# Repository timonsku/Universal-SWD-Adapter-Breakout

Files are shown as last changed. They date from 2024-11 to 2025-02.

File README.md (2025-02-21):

# Universal-SWD-Adapter-Breakout

A simple PCB to adapt between common SWD connector variations.
- 20pin 0.1" Cortex SWD connector (as found on the big J-Link's)
- 10pin 0.1" Cortex SWD connector (as found on ST-Link)
- 10pin 0.05" Cortex SWD connector (as found on J-Link Mini and many targets) 
- Named 0.1" pin header row for all 6 main signals
- 6pin 0.1" TC2030-IDC footprint (compact "SWD-Adapter" only) 

There are two variants, one compact version and an expanded version that add an RJ12 connector intended to be used with the TC2030-MCP-NL Tag Connect cables which are used on Microchip programmers and are often the cheapest and easiest to buy Tag Connect cable from distributors. This variant is also useful for having some solder on pads for hard wiring an SWD connection to a device.

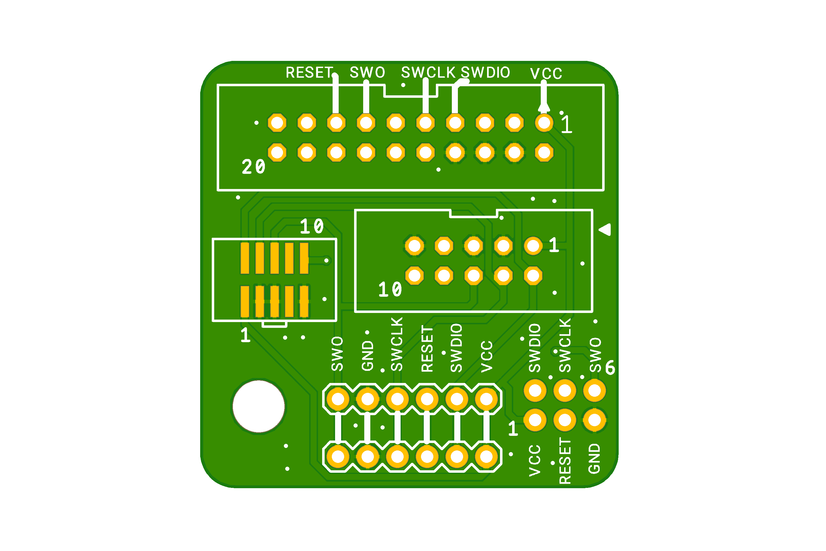
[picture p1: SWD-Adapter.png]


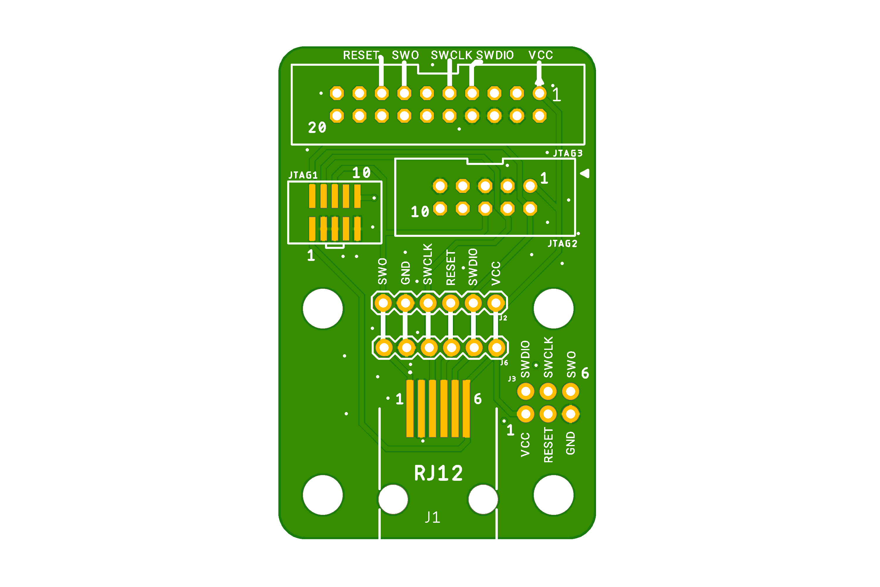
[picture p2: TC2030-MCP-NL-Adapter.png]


BOM
----

- Molex 95501-6669 (RJ12)
- Samtec FTSH-105-01-L-DV-K-TR (2x5 pin 1.27mm SMT shrouded). Cheaper here on AliExpress: https://s.click.aliexpress.com/e/_DmALpMt
- Molex 90130-1110 (2x5 2.54mm PTH Shrouded)
- Molex 90130-1120 (2x10 2.54mm PTH Shrouded)

Various distributor PNs the RJ12 tag connect cable:

NL version:
- 579-TC2030-MCP-NL 

With hooks:
- 733-53025-851
- 579-TC2030-MCP

For DigiKey:
- TC2030-MCP-NLTC-ND
- TC2030-MCPTC-ND

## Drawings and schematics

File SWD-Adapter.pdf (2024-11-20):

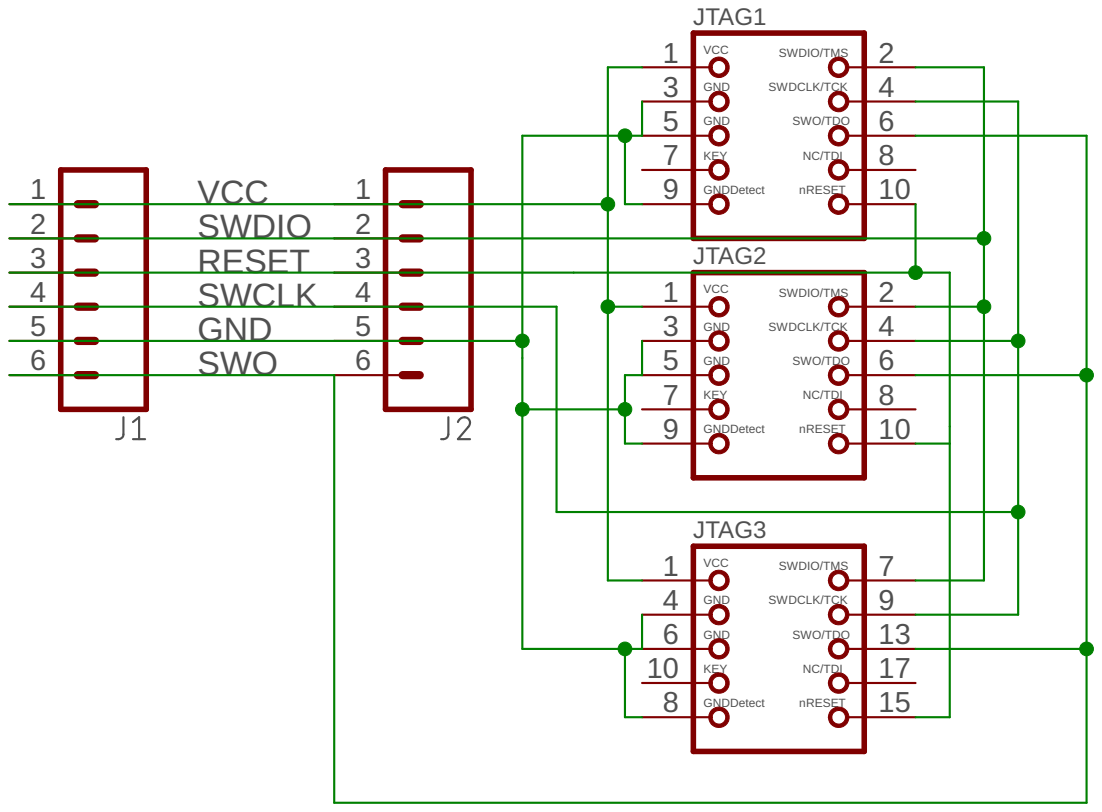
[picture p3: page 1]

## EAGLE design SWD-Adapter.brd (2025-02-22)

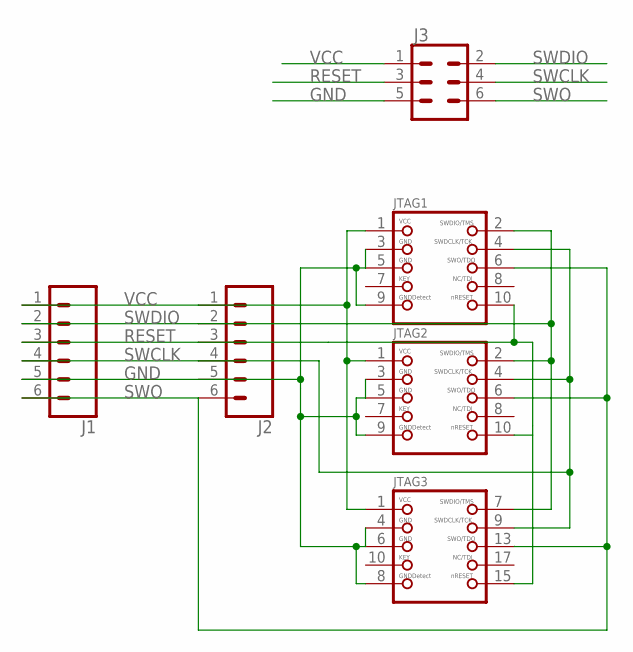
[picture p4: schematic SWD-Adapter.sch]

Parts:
J1, J2: CONN_06SILK_FEMALE_PTH; 1X06
J3: CONN_03X2NO_SILK; 2X3-NS
JTAG1: JTAG-CORTEXM3; 2X05_1.27MM_SMT
JTAG2: JTAG-CORTEXM3MOLEX; CORTEXM3_SWD10_MOLEX
JTAG3: JTAG-CORTEXM3MOLEX20; JTAG-ARM

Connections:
GND: J1.5, J2.5, J3.5, JTAG1.3, JTAG1.5, JTAG1.9, JTAG2.3, JTAG2.5, JTAG2.9, JTAG3.4 (3), JTAG3.6 (5), JTAG3.8 (9)
RESET: J1.3, J2.3, J3.3, JTAG1.10, JTAG2.10, JTAG3.15 (10)
SWCLK: J1.4, J2.4, J3.4, JTAG1.4, JTAG2.4, JTAG3.9 (4)
SWDIO: J1.2, J2.2, J3.2, JTAG1.2, JTAG2.2, JTAG3.7 (2)
SWO: J1.6, J2.6, J3.6, JTAG1.6, JTAG2.6, JTAG3.13 (6)
VCC: J1.1, J2.1, J3.1, JTAG1.1, JTAG2.1, JTAG3.1

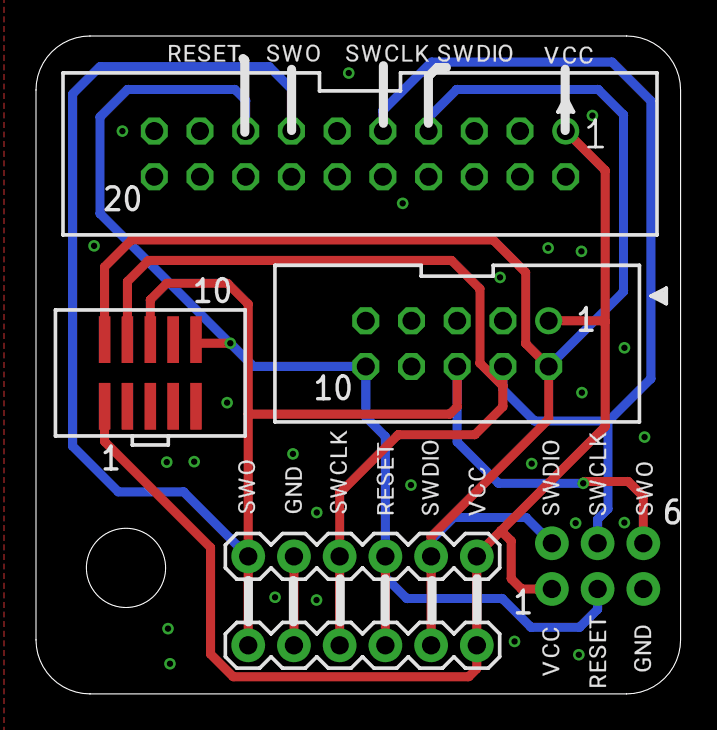
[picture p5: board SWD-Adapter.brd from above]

Board: 2 copper layers, 35.8 x 36.5 mm, 23 parts (0 on the bottom side), 6 nets.

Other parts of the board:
U$1, U$7, U$12: SWO0
U$2, U$15: GND0
U$3, U$11, U$16: SWCLK0
U$4, U$9, U$13: RESET0
U$5, U$8, U$17: SWDIO0
U$6, U$10, U$14: VCC0

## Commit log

2024-11-20 add compact variant
    [SWD-Adapter.brd, SWD-Adapter.sch]
2025-02-21 add 6pin TC2030 pinout to SWD-Adapter variant
    [SWD-Adapter.brd, SWD-Adapter.sch]
2025-02-21 update RJ12 variant with 6p connector
    [TC2030-MCP-NL-Adapter.brd, TC2030-MCP-NL-Adapter.sch]
2025-02-22 update board file
    [SWD-Adapter.brd]

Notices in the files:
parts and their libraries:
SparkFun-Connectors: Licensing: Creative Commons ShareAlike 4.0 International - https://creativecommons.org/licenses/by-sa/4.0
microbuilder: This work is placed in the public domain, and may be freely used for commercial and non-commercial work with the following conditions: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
